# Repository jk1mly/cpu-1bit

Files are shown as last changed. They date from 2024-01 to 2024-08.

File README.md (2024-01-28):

# cpu-1bit
MC14500 1bit CPU

MC14500Bを使って実験を行うための基板と、プログラムをEPROMの代わりにPICに入れるソフト
MC14500Bのソフトはprogcd.hに記述
ニーモニックどはopcode.hに定義
main.cはアドレスに従ってデータを出すのみ
PICでの遅延が大きいので16F1938を32Mで動かしている
（あくまでもMC14500Bを使うのが目的）

ICソケットに実装する前に電源のショートなど確認する
電池を入れて電源を供給、PWRのLEDで電源極性を確認
電源を切ってICを実装、向きがバラバラなので注意
J3はS；スロー側に設定、ジャンパポストはオープンで良い
IN(J10)とOUT(J4)のb1、INのb2をGND(J6 3)、b3を+V(J6 1)に接続
（テスト用のプログラムだけならb3のみで良い、接続はプログラムに依存）
電源を入れて異常がなければPICkitを接続
（PICkitからは電源を供給しない・デフォルト）
PICにプログラムしたらPICkitを外す
RUNのスイッチを押すとプルグラムが動く

（PICで動かすなら3Vか4.5V）
SW4を押すとCPUがリセットされる
同時にROMアドレスの上位が1になりEPROMの書き込んでない領域になる
これによりCPUにはFが入力されるのでFLGFが出てぷrグラムカウンタが0になる
試験用のプログラムはDIPスイッチのNOT, AND, OR, XORをLEDに表示する

改善点
SW4とパラに0.1uFを入れておいた方が良い
（電源ON時にリセット状態で止められる・動かしたいならSW3）
RUNとWRITEのLEDを付けておいた方が良い
データとして0,1、ラッチしたデータを読める入力があった方が良い
（ジャンパするよう基板を作ってあるが、ジャンパポストを設けるべき）
ラッチ4ビットのLEDに入れる抵抗は別回路な方が良い
（外部I/Oで使うための抵抗と兼用になっている）

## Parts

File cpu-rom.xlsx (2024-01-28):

# | Reference | Qty | Value | Footprint |  | Akizuki
1 | C1, C2, C3, C4, C5, C7, C9, C10, C11, C13, C14, C15 | 12 | 0.1u | 積層磁器コン |  | 113582
2 | C6, C8 | 2 | 1000p | 積層磁器コン |  | 104062
3 | C12 | 1 | 10u | 電界コン |  | 117897
4 | D1, D2, D3, D4 | 7 | LED | LED 緑 |  | 111639
 | D6, D7, D8 | 3 | LED | LED 黄 |  | 111637
5 | D5 | 1 | D | スイッチングダイオード |  | 100941
6 | IC1 | 1 | MC14001 | NOR |  | 114536
7 | IC2 | 1 | MC14099 | ラッチ |  |  | Sato
8 | IC3 | 1 | PIC16F1938 | PIC（ROM代用） |  | 104357
9 | IC4 | 1 | MC14049 | INV |  | 109417
10 | IC5 | 1 | MC14500B | 1bit CPU |  |  | AliEx
11 | IC6 | 1 | TMM2764 | EPROM | 未実装 |  | Suzusho
12 | IC7 | 1 | MC14011 | NAND |  | 113729
13 | IC8 | 1 | MC14520 | カウンタ |  | 110918
14 | IC9 | 1 | MC14512 | セレクタ |  |  | Sato
 | IC1,7 | 2 |  | Socket 14P |  | 100029
 | IC2,4,5,8,9 | 5 |  | Socket 16P |  | 100029
 | IC3 | 1 |  | Socket 28P 300mil |  | 101339
 | IC6 | 1 |  | Socket 28P 600mil |  | 100033
15 | J1 | 1 | Conn_06 | PICkit接続用 |  | 112247
16 | J2, J7, J8 | 4 | Conn_01x03_Pin | ジャンパポスト |  | 112247
 | J2, J7, J8 | 1 |  | ジャンパピン |  | 103691
 | J3 | 1 |  | スイッチ |  | 115707
17 | J4, J5, J10, J11 | 4 | Conn_08 | 外部接続用 |  | 100082
18 | J6 | 1 | Conn_01x05_Pin | 外部接続用 |  | 112247
19 | J9 | 1 | Conn_02 | 電池用 |  | 112247
 | J9 | 1 |  | 電池ケース |  | 112244
20 | R1, R2, R4, R6, R7, R19, R31, R32 | 8 | 10k | 抵抗 |  | 118208
21 | R3, R5, R8, R9, R10, R11, R12, R13, R14, R15, R23, R26, R29, R30, R35, R36, R39, R40, R44, R45 | 20 | 100 | 抵抗 |  | 118208
22 | R16 | 1 | 1M | 抵抗 |  | 125105
23 | R17 | 1 | 47k | 抵抗 |  | 118208
24 | R18 | 1 | 1k | 抵抗 | 未実装
25 | R20 | 1 | 22 | 抵抗 |  | 125221
26 | R21 | 1 | 220 | 抵抗 |  | 125221
27 | R22, R24, R41 | 3 | 470 | 抵抗 |  | 125471
28 | R25, R27, R28, R33, R34, R37, R38, R42, R43 | 9 | 100k | 抵抗 |  | 125104
29 | SW1, SW2, SW3, SW4 | 4 | SW_Push | タクトスイッチ |  | 108080
30 | SW5 | 1 | SW_DIP_x04 | DIPスイッチ |  | 115243
31 | TP1, TP2, TP3, TP4 | 4 | M2.6 | スペーサ | 未実装 | 107318
 | TP1, TP2, TP3, TP4 | 4 | M2.6 | ナット | 未実装 | 114371
32 | TP5, TP6 | 2 |  | チェック端子 | 未実装 | 107591

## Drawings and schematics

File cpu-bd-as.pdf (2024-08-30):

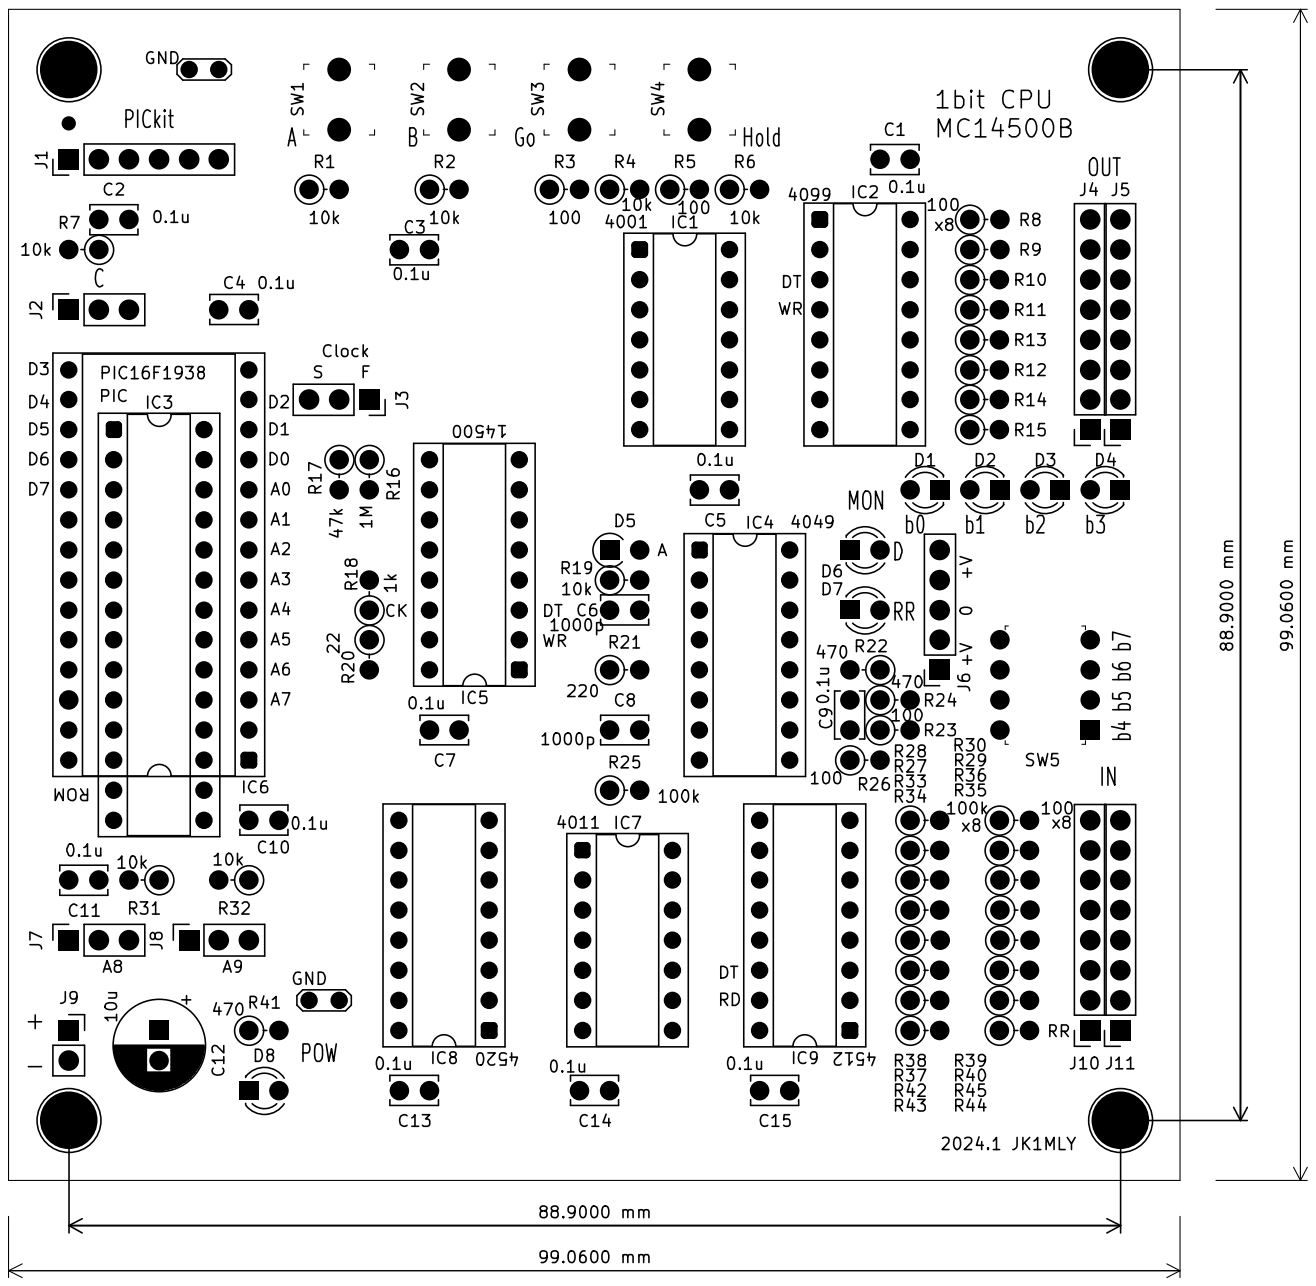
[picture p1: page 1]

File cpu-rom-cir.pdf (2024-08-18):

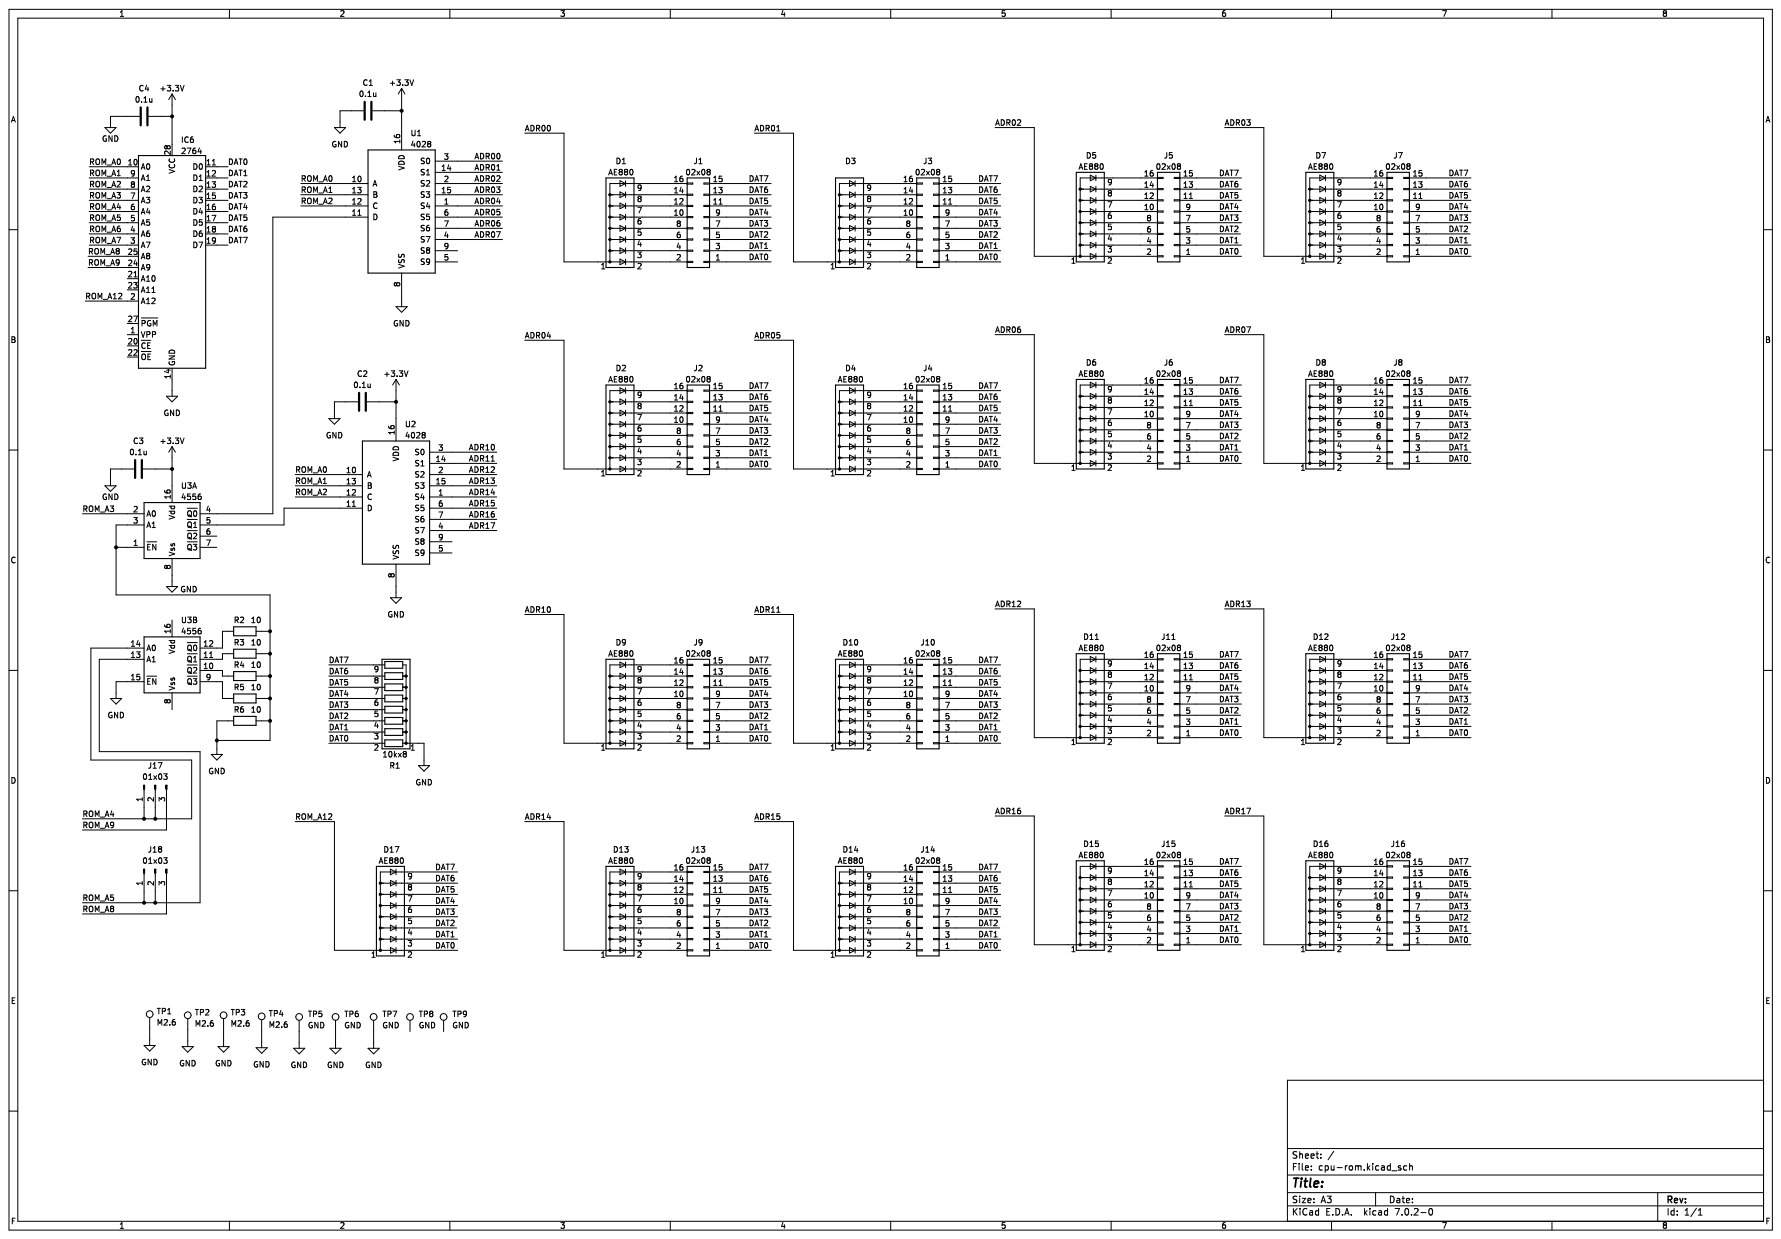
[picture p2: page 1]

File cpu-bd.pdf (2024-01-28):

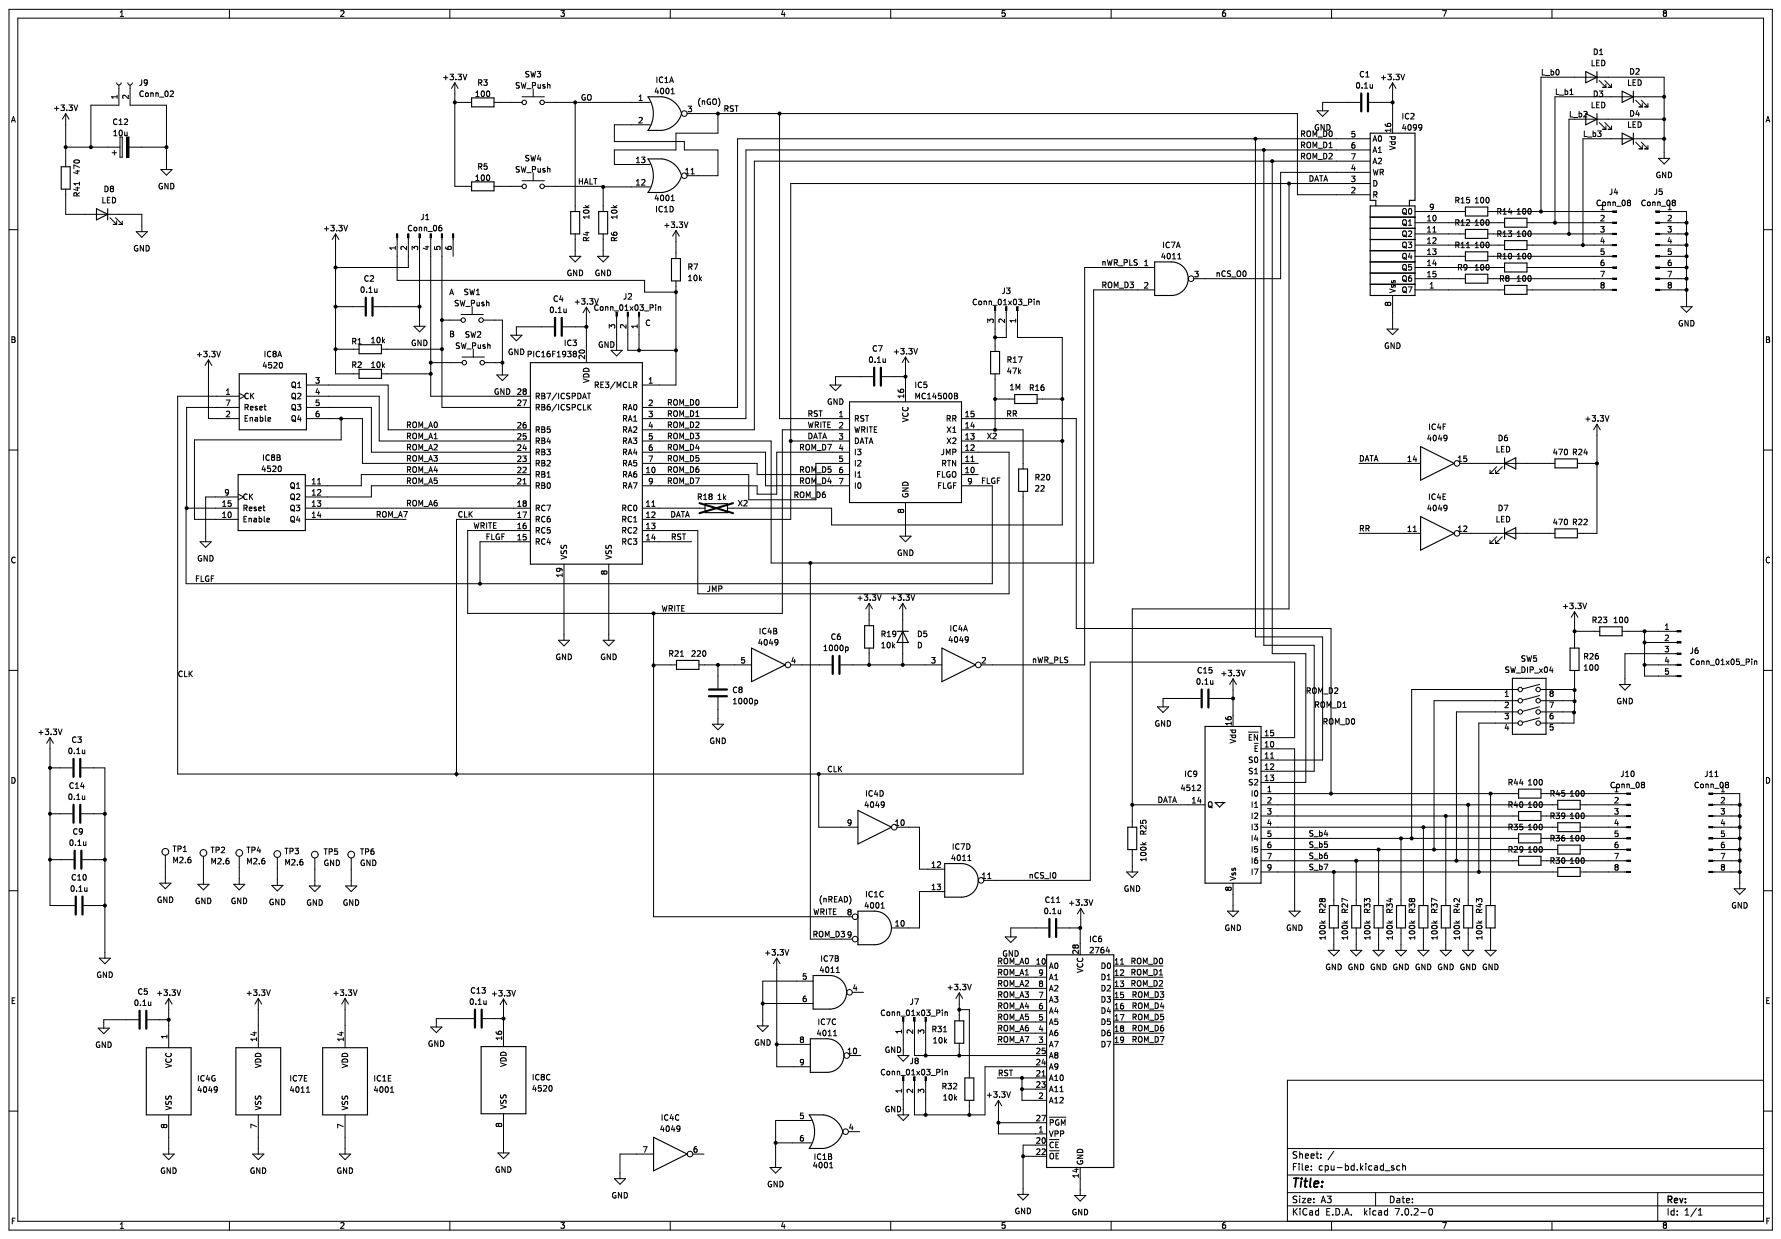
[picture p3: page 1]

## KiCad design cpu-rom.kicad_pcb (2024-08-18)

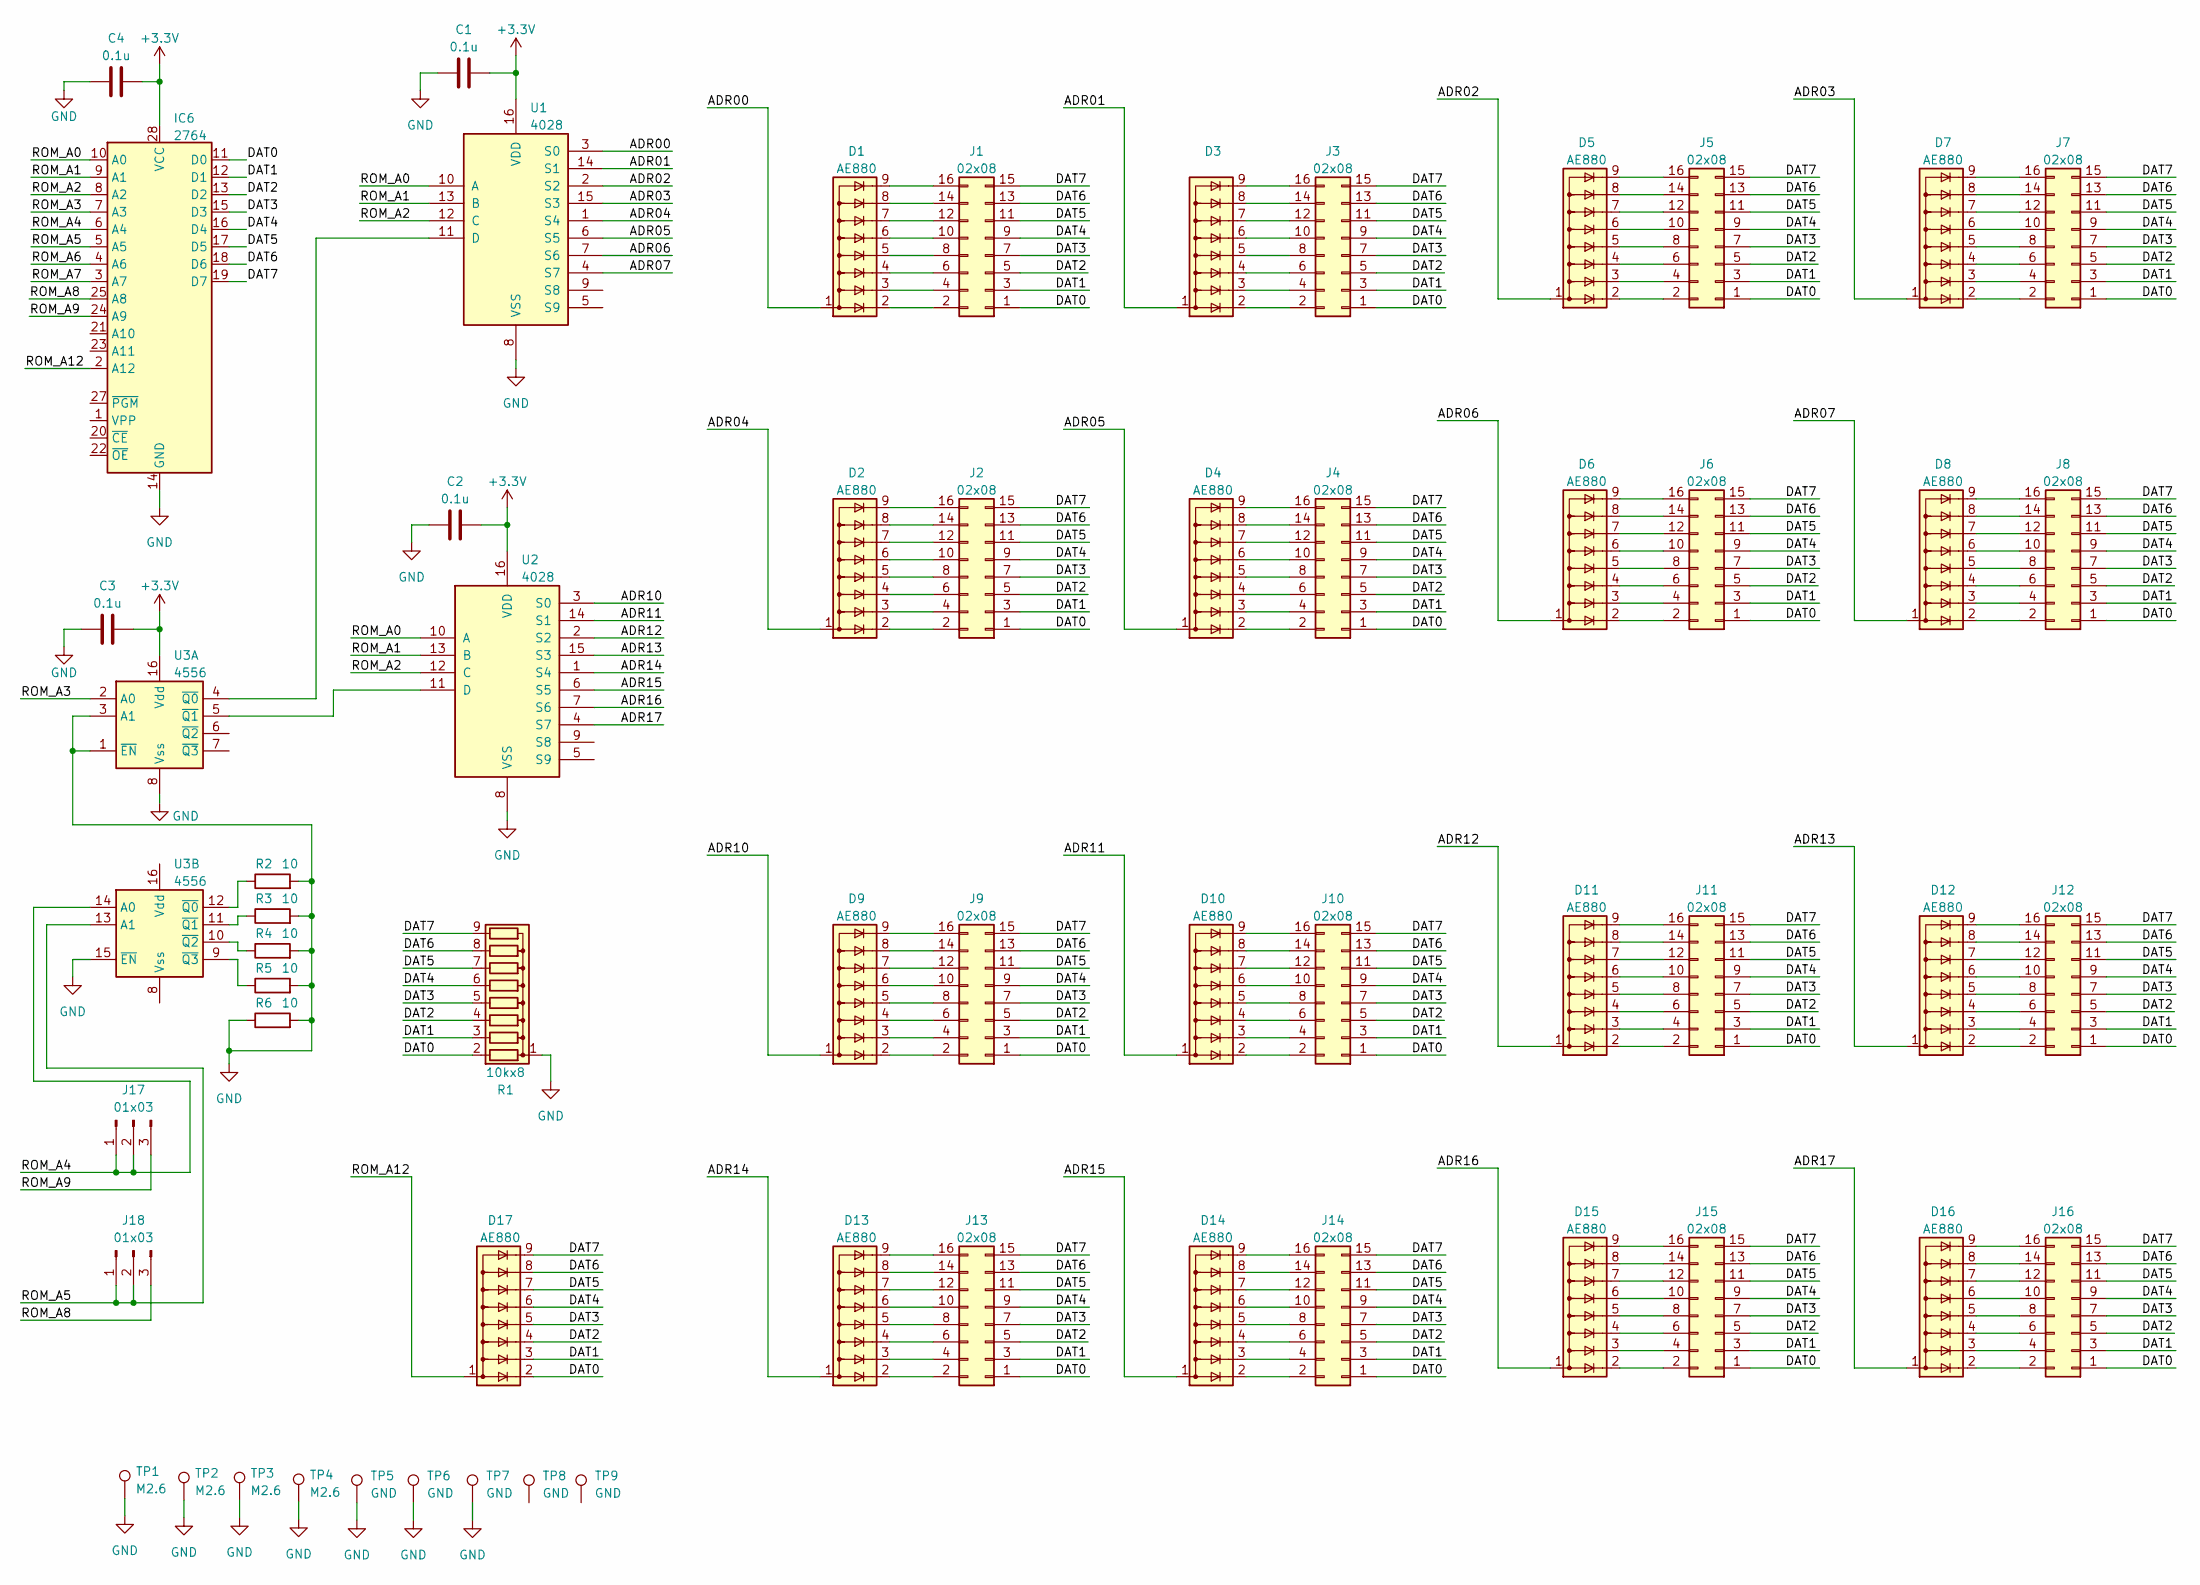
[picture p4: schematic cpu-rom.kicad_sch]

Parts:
C1, C2, C3, C4: 0.1u; C_Disc_P2.54mm
D1, D2, D3, D4, D5, D6, D7, D8, D9, D10, D11, D12, D13, D14, D15, D16, D17: AE880; R_Array_SIP9
IC6: 2764; DIP-28_W15.24mm_Socket_mini
J1, J2, J3, J4, J5, J6, J7, J8, J9, J10, J11, J12, J13, J14, J15, J16: 02x08; PinHeader_2x08_P2.54mm_Vertical
J17, J18: 01x03; PinHeader_1x03_P2.54mm_Vertical
R1: 10kx8; R_Array_SIP9
R2, R3, R4, R5, R6: 10; R_Axial_DIN0207_L6.3mm_D2.2mm_P2.54mm_Vertical
TP1, TP2, TP3, TP4: M2.6; TestPoint_Drill3mm
TP5, TP6, TP7, TP8, TP9: GND; TestPoint_2Pads_Pitch2.54mm_Drill0.8mm
U1, U2: 4028; DIP-16_W7.62mm_Socket_mini
U3: 4556; DIP-16_W7.62mm_Socket_mini

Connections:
+3.3V: C1.2, C2.2, C3.2, C4.2, IC6.28 (VCC), U1.16 (VDD), U2.16 (VDD), U3.16 (Vdd)
/ADR00: D1.1 (common), U1.3 (S0)
/ADR01: D3.1 (common), U1.14 (S1)
/ADR02: D5.1 (common), U1.2 (S2)
/ADR03: D7.1 (common), U1.15 (S3)
/ADR04: D2.1 (common), U1.1 (S4)
/ADR05: D4.1 (common), U1.6 (S5)
/ADR06: D6.1 (common), U1.7 (S6)
/ADR07: D8.1 (common), U1.4 (S7)
/ADR10: D9.1 (common), U2.3 (S0)
/ADR11: D10.1 (common), U2.14 (S1)
/ADR12: D11.1 (common), U2.2 (S2)
/ADR13: D12.1 (common), U2.15 (S3)
/ADR14: D13.1 (common), U2.1 (S4)
/ADR15: D14.1 (common), U2.6 (S5)
/ADR16: D15.1 (common), U2.7 (S6)
/ADR17: D16.1 (common), U2.4 (S7)
/DAT0: D17.2 (R1), IC6.11 (D0), J1.1, J2.1, J3.1, J4.1, J5.1, J6.1, J7.1, J8.1, J9.1, J10.1, J11.1, J12.1, J13.1, J14.1, J15.1, J16.1, R1.2 (R1)
/DAT1: D17.3 (R2), IC6.12 (D1), J1.3, J2.3, J3.3, J4.3, J5.3, J6.3, J7.3, J8.3, J9.3, J10.3, J11.3, J12.3, J13.3, J14.3, J15.3, J16.3, R1.3 (R2)
/DAT2: D17.4 (R3), IC6.13 (D2), J1.5, J2.5, J3.5, J4.5, J5.5, J6.5, J7.5, J8.5, J9.5, J10.5, J11.5, J12.5, J13.5, J14.5, J15.5, J16.5, R1.4 (R3)
/DAT3: D17.5 (R4), IC6.15 (D3), J1.7, J2.7, J3.7, J4.7, J5.7, J6.7, J7.7, J8.7, J9.7, J10.7, J11.7, J12.7, J13.7, J14.7, J15.7, J16.7, R1.5 (R4)
/DAT4: D17.6 (R5), IC6.16 (D4), J1.9, J2.9, J3.9, J4.9, J5.9, J6.9, J7.9, J8.9, J9.9, J10.9, J11.9, J12.9, J13.9, J14.9, J15.9, J16.9, R1.6 (R5)
/DAT5: D17.7 (R6), IC6.17 (D5), J1.11, J2.11, J3.11, J4.11, J5.11, J6.11, J7.11, J8.11, J9.11, J10.11, J11.11, J12.11, J13.11, J14.11, J15.11, J16.11, R1.7 (R6)
/DAT6: D17.8 (R7), IC6.18 (D6), J1.13, J2.13, J3.13, J4.13, J5.13, J6.13, J7.13, J8.13, J9.13, J10.13, J11.13, J12.13, J13.13, J14.13, J15.13, J16.13, R1.8 (R7)
/DAT7: D17.9 (R8), IC6.19 (D7), J1.15, J2.15, J3.15, J4.15, J5.15, J6.15, J7.15, J8.15, J9.15, J10.15, J11.15, J12.15, J13.15, J14.15, J15.15, J16.15, R1.9 (R8)
/ROM_A0: IC6.10 (A0), U1.10 (A), U2.10 (A)
/ROM_A1: IC6.9 (A1), U1.13 (B), U2.13 (B)
/ROM_A2: IC6.8 (A2), U1.12 (C), U2.12 (C)
/ROM_A3: IC6.7 (A3), U3.2 (A0)
/ROM_A4: IC6.6 (A4), J17.1, J17.2, U3.14 (A0)
/ROM_A5: IC6.5 (A5), J18.1, J18.2, U3.13 (A1)
/ROM_A6: IC6.4 (A6)
/ROM_A7: IC6.3 (A7)
/ROM_A8: IC6.25 (A8), J18.3
/ROM_A9: IC6.24 (A9), J17.3
/ROM_A12: D17.1 (common), IC6.2 (A12)
GND: C1.1, C2.1, C3.1, C4.1, IC6.14 (GND), R1.1 (common), R2.2, R3.2, R4.2, R5.2, R6.1, R6.2, TP1.1, TP2.1, TP3.1, TP4.1, TP5.1, TP6.1, TP7.1, U1.8 (VSS), U2.8 (VSS), U3.1 (~EN), U3.3 (A1), U3.8 (Vss), U3.15 (~EN)
unnamed: D1.2 (R1), J1.2
unnamed: D1.3 (R2), J1.4
unnamed: D1.4 (R3), J1.6
unnamed: D1.5 (R4), J1.8
unnamed: D1.6 (R5), J1.10
unnamed: D1.7 (R6), J1.12
unnamed: D1.8 (R7), J1.14
unnamed: D1.9 (R8), J1.16
unnamed: D2.2 (R1), J2.2
unnamed: D2.3 (R2), J2.4
unnamed: D2.4 (R3), J2.6
unnamed: D2.5 (R4), J2.8
unnamed: D2.6 (R5), J2.10
unnamed: D2.7 (R6), J2.12
unnamed: D2.8 (R7), J2.14
unnamed: D2.9 (R8), J2.16
unnamed: D3.2 (R1), J3.2
unnamed: D3.3 (R2), J3.4
unnamed: D3.4 (R3), J3.6
unnamed: D3.5 (R4), J3.8
unnamed: D3.6 (R5), J3.10
unnamed: D3.7 (R6), J3.12
unnamed: D3.8 (R7), J3.14
unnamed: D3.9 (R8), J3.16
unnamed: D4.2 (R1), J4.2
unnamed: D4.3 (R2), J4.4
unnamed: D4.4 (R3), J4.6
unnamed: D4.5 (R4), J4.8
unnamed: D4.6 (R5), J4.10
unnamed: D4.7 (R6), J4.12
unnamed: D4.8 (R7), J4.14
unnamed: D4.9 (R8), J4.16
unnamed: D5.2 (R1), J5.2
unnamed: D5.3 (R2), J5.4
unnamed: D5.4 (R3), J5.6
unnamed: D5.5 (R4), J5.8
unnamed: D5.6 (R5), J5.10
unnamed: D5.7 (R6), J5.12
unnamed: D5.8 (R7), J5.14
unnamed: D5.9 (R8), J5.16
unnamed: D6.2 (R1), J6.2
unnamed: D6.3 (R2), J6.4
unnamed: D6.4 (R3), J6.6
unnamed: D6.5 (R4), J6.8
unnamed: D6.6 (R5), J6.10
unnamed: D6.7 (R6), J6.12
unnamed: D6.8 (R7), J6.14
unnamed: D6.9 (R8), J6.16
unnamed: D7.2 (R1), J7.2
unnamed: D7.3 (R2), J7.4
unnamed: D7.4 (R3), J7.6
unnamed: D7.5 (R4), J7.8
unnamed: D7.6 (R5), J7.10
unnamed: D7.7 (R6), J7.12
unnamed: D7.8 (R7), J7.14
unnamed: D7.9 (R8), J7.16
unnamed: D8.2 (R1), J8.2
unnamed: D8.3 (R2), J8.4
unnamed: D8.4 (R3), J8.6
unnamed: D8.5 (R4), J8.8
unnamed: D8.6 (R5), J8.10
unnamed: D8.7 (R6), J8.12
unnamed: D8.8 (R7), J8.14
unnamed: D8.9 (R8), J8.16
unnamed: D9.2 (R1), J9.2
unnamed: D9.3 (R2), J9.4
unnamed: D9.4 (R3), J9.6
unnamed: D9.5 (R4), J9.8
unnamed: D9.6 (R5), J9.10
unnamed: D9.7 (R6), J9.12
unnamed: D9.8 (R7), J9.14
unnamed: D9.9 (R8), J9.16
unnamed: D10.2 (R1), J10.2
unnamed: D10.3 (R2), J10.4
unnamed: D10.4 (R3), J10.6
unnamed: D10.5 (R4), J10.8
unnamed: D10.6 (R5), J10.10
unnamed: D10.7 (R6), J10.12
unnamed: D10.8 (R7), J10.14
unnamed: D10.9 (R8), J10.16
unnamed: D11.2 (R1), J11.2
unnamed: D11.3 (R2), J11.4
unnamed: D11.4 (R3), J11.6
unnamed: D11.5 (R4), J11.8
unnamed: D11.6 (R5), J11.10
unnamed: D11.7 (R6), J11.12
unnamed: D11.8 (R7), J11.14
unnamed: D11.9 (R8), J11.16
unnamed: D12.2 (R1), J12.2
unnamed: D12.3 (R2), J12.4
unnamed: D12.4 (R3), J12.6
unnamed: D12.5 (R4), J12.8
unnamed: D12.6 (R5), J12.10
unnamed: D12.7 (R6), J12.12
unnamed: D12.8 (R7), J12.14
unnamed: D12.9 (R8), J12.16
unnamed: D13.2 (R1), J13.2
unnamed: D13.3 (R2), J13.4
unnamed: D13.4 (R3), J13.6
unnamed: D13.5 (R4), J13.8
unnamed: D13.6 (R5), J13.10
unnamed: D13.7 (R6), J13.12
unnamed: D13.8 (R7), J13.14
unnamed: D13.9 (R8), J13.16
unnamed: D14.2 (R1), J14.2
unnamed: D14.3 (R2), J14.4
unnamed: D14.4 (R3), J14.6
unnamed: D14.5 (R4), J14.8
unnamed: D14.6 (R5), J14.10
unnamed: D14.7 (R6), J14.12
unnamed: D14.8 (R7), J14.14
unnamed: D14.9 (R8), J14.16
unnamed: D15.2 (R1), J15.2
unnamed: D15.3 (R2), J15.4
unnamed: D15.4 (R3), J15.6
unnamed: D15.5 (R4), J15.8
unnamed: D15.6 (R5), J15.10
unnamed: D15.7 (R6), J15.12
unnamed: D15.8 (R7), J15.14
unnamed: D15.9 (R8), J15.16
unnamed: D16.2 (R1), J16.2
unnamed: D16.3 (R2), J16.4
unnamed: D16.4 (R3), J16.6
unnamed: D16.5 (R4), J16.8
unnamed: D16.6 (R5), J16.10
unnamed: D16.7 (R6), J16.12
unnamed: D16.8 (R7), J16.14
unnamed: D16.9 (R8), J16.16
unnamed: U1.11 (D), U3.4 (~Q0)
unnamed: U2.11 (D), U3.5 (~Q1)
unnamed: R2.1, U3.12 (~Q0)
unnamed: R3.1, U3.11 (~Q1)
unnamed: R4.1, U3.10 (~Q2)
unnamed: R5.1, U3.9 (~Q3)

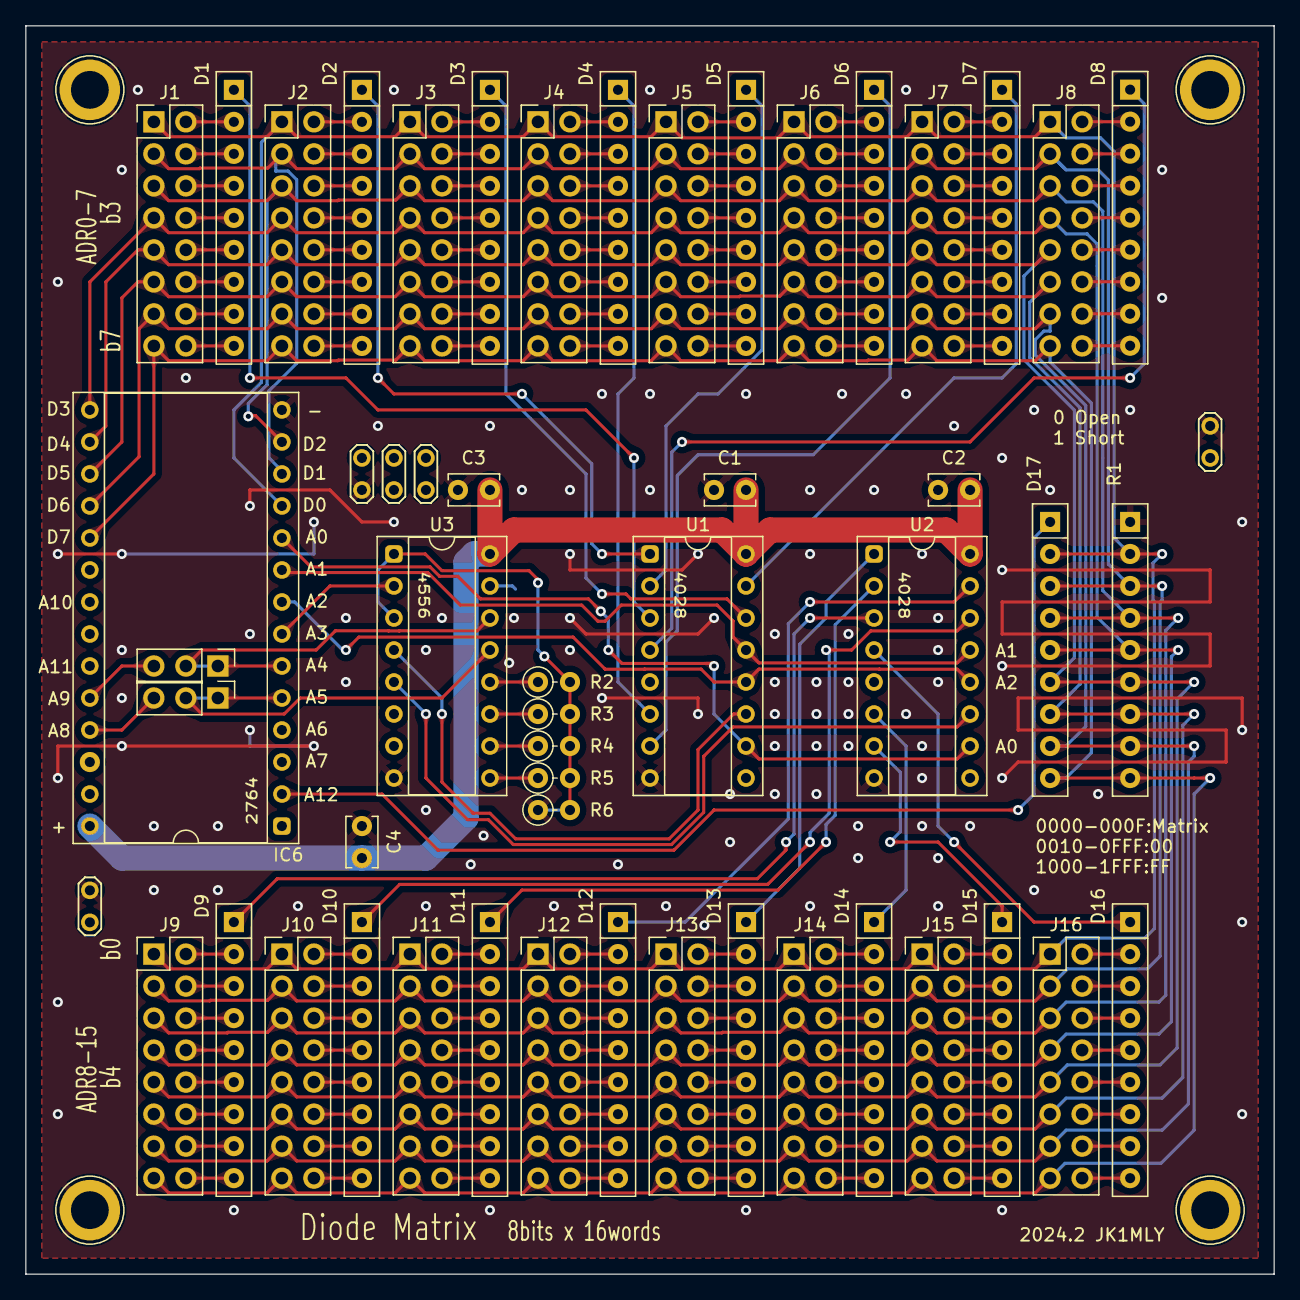
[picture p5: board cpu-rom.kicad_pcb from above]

Board: 2 copper layers, 99.1 x 99.1 mm, 58 parts (0 on the bottom side), 169 nets.

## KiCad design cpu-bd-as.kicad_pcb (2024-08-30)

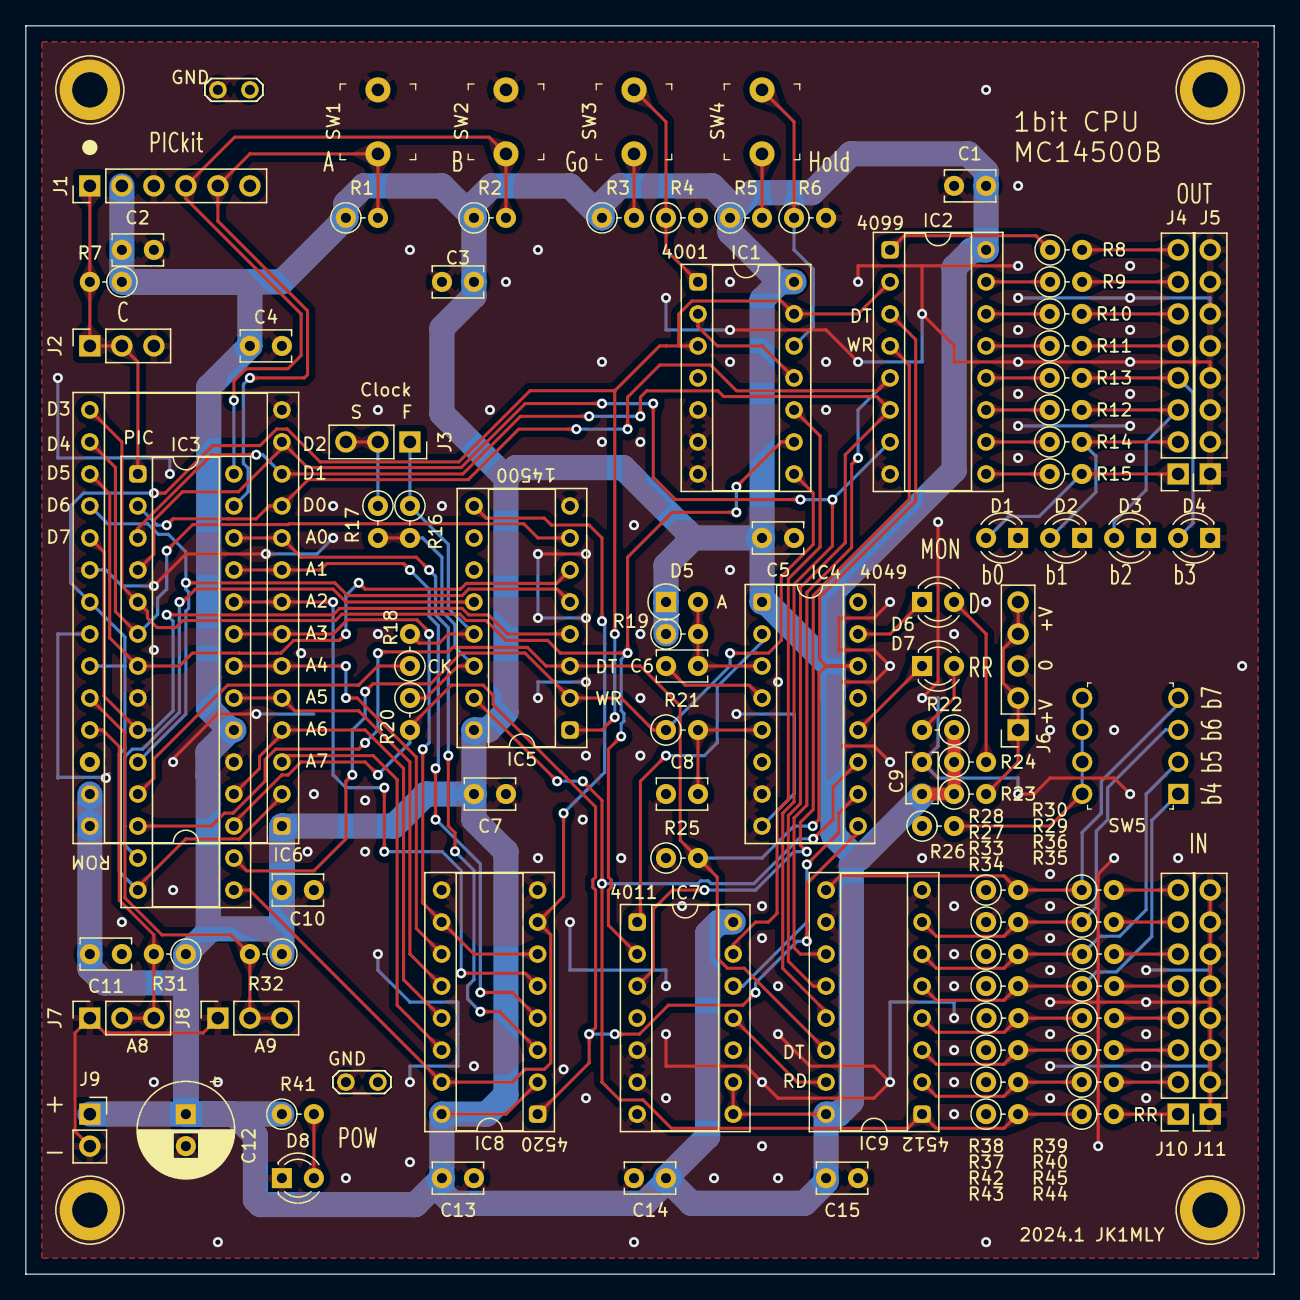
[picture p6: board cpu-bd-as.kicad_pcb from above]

Board: 2 copper layers, 99.1 x 99.1 mm, 99 parts (0 on the bottom side), 85 nets.

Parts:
C1, C2, C3, C4, C5, C7, C9, C10, C11, C13, C14, C15: 0.1u; C_Disc_P2.54mm
C6, C8: 1000p; C_Disc_P2.54mm
C12: 10u; CP_Radial_D7.5mm_P2.54mm
D1, D2, D3, D4, D6, D7, D8: LED; LED_D3.0mm
D5: D; D_A-405_P2.54mm_Vertical_AnodeUp
IC1: 4001; DIP-14_W7.62mm_Socket_mini
IC2: 4099; DIP-16_W7.62mm_Socket_mini
IC3: PIC16F1938; DIP-28_W7.62mm_Socket_mini
IC4: 4049; DIP-16_W7.62mm_Socket_mini
IC5: MC14500B; DIP-16_W7.62mm_Socket_mini
IC6: 2764; DIP-28_W15.24mm_Socket_mini
IC7: 4011; DIP-14_W7.62mm_Socket_mini
IC8: 4520; DIP-16_W7.62mm_Socket_mini
IC9: 4512; DIP-16_W7.62mm_Socket_mini
J1: Conn_06; PinHeader_1x06_P2.54mm_Vertical
J2, J3, J7, J8: Conn_01x03_Pin; PinSocket_1x03_P2.54mm_Vertical
J4, J5, J10, J11: Conn_08; PinSocket_1x08_P2.54mm_Vertical
J6: Conn_01x05_Pin; PinSocket_1x05_P2.54mm_Vertical
J9: Conn_02; PinSocket_1x02_P2.54mm_Vertical
R1, R2, R4, R6, R7, R19, R31, R32: 10k; R_Axial_DIN0207_L6.3mm_D2.2mm_P2.54mm_Vertical
R3, R5, R8, R9, R10, R11, R12, R13, R14, R15, R23, R26, R29, R30, R35, R36, R39, R40, R44, R45: 100; R_Axial_DIN0207_L6.3mm_D2.2mm_P2.54mm_Vertical
R16: 1M; R_Axial_DIN0207_L6.3mm_D2.2mm_P2.54mm_Vertical
R17: 47k; R_Axial_DIN0207_L6.3mm_D2.2mm_P2.54mm_Vertical
R18: 1k; R_Axial_DIN0207_L6.3mm_D2.2mm_P2.54mm_Vertical
R20: 22; R_Axial_DIN0207_L6.3mm_D2.2mm_P2.54mm_Vertical
R21: 220; R_Axial_DIN0207_L6.3mm_D2.2mm_P2.54mm_Vertical
R22, R24, R41: 470; R_Axial_DIN0207_L6.3mm_D2.2mm_P2.54mm_Vertical
R25, R27, R28, R33, R34, R37, R38, R42, R43: 100k; R_Axial_DIN0207_L6.3mm_D2.2mm_P2.54mm_Vertical
SW1, SW2, SW3, SW4: SW_Push; Switch_2P
SW5: SW_DIP_x04; DIP-8_W7.62mm
TP1, TP2, TP3, TP4: M2.6; TestPoint_Loop_D3.80mm_Drill2.8mm
TP5, TP6: GND; TestPoint_2Pads_Pitch2.54mm_Drill0.8mm

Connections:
+3.3V: C1.2, C2.1, C3.1, C4.2, C5.2, C7.2, C9.1, C10.1, C11.2, C12.1, C13.2, C14.1, C15.2, D5.1 (K), IC1.14 (VDD), IC2.16 (Vdd), IC3.20 (VDD), IC4.1 (VCC), IC5.16 (VCC), IC6.1 (VPP), IC6.27 (~PGM), IC6.28 (VCC), IC7.8, IC7.9, IC7.14 (VDD), IC8.2 (Enable), IC8.16 (VDD), IC9.16 (Vdd), J1.2, J9.1, R1.1, R2.1, R3.1, R5.1, R7.1, R19.1, R22.1, R23.1, R24.1, R26.1, R31.1, R32.1, R41.1
/CLK: IC3.17 (RC6), IC4.9, IC8.1 (CK), R20.2
/DATA: IC2.3 (D), IC3.12 (RC1), IC4.14, IC5.3 (DATA), IC9.14 (Q), R25.2
/FLGF: IC3.15 (RC4), IC5.9 (FLGF), IC8.7 (Reset), IC8.15 (Reset)
/GO: IC1.1, R4.1, SW3.2
/HALT: IC1.12, R6.1, SW4.2
/JMP: IC3.13 (RC2), IC5.12 (JMP)
/L_b0: D1.2 (A), J4.1, R15.2
/L_b1: D2.2 (A), J4.2, R14.2
/L_b2: D3.2 (A), J4.3, R12.2
/L_b3: D4.2 (A), J4.4, R13.2
/ROM_A0: IC3.26 (RB5), IC6.10 (A0), IC8.3 (Q1)
/ROM_A1: IC3.25 (RB4), IC6.9 (A1), IC8.4 (Q2)
/ROM_A2: IC3.24 (RB3), IC6.8 (A2), IC8.5 (Q3)
/ROM_A3: IC3.23 (RB2), IC6.7 (A3), IC8.6 (Q4), IC8.10 (Enable)
/ROM_A4: IC3.22 (RB1), IC6.6 (A4), IC8.11 (Q1)
/ROM_A5: IC3.21 (RB0), IC6.5 (A5), IC8.12 (Q2)
/ROM_A6: IC3.18 (RC7), IC6.4 (A6), IC8.13 (Q3)
/ROM_A7: IC6.3 (A7), IC8.14 (Q4)
/ROM_D0: IC2.5 (A0), IC3.2 (RA0), IC6.11 (D0), IC9.11 (S0)
/ROM_D1: IC2.6 (A1), IC3.3 (RA1), IC6.12 (D1), IC9.12 (S1)
/ROM_D2: IC2.7 (A2), IC3.4 (RA2), IC6.13 (D2), IC9.13 (S2)
/ROM_D3: IC1.9, IC3.5 (RA3), IC6.15 (D3), IC7.2
/ROM_D4: IC3.6 (RA4), IC5.7 (I0), IC6.16 (D4)
/ROM_D5: IC3.7 (RA5), IC5.6 (I1), IC6.17 (D5)
/ROM_D6: IC3.10 (RA6), IC5.5 (I2), IC6.18 (D6)
/ROM_D7: IC3.9 (RA7), IC5.4 (I3), IC6.19 (D7)
/RR: IC4.11, IC5.15 (RR), IC9.1 (I0), R43.2, R44.1
/RST: IC1.3, IC1.13, IC2.2 (R), IC3.14 (RC3), IC5.1 (RST), IC6.2 (A12), IC6.21 (A10), IC6.23 (A11)
/S_b4: IC9.5 (I4), R34.2, R35.1, SW5.1
/S_b5: IC9.6 (I5), R33.2, R36.1, SW5.2
/S_b6: IC9.7 (I6), R27.2, R29.1, SW5.3
/S_b7: IC9.9 (I7), R28.2, R30.1, SW5.4
/WRITE: IC1.8, IC3.16 (RC5), IC5.2 (WRITE), R21.1
/X2: IC5.13 (X2), J3.1, R16.1, R18.2
/nCS_I0: IC7.11, IC9.15 (~EN)
/nCS_O0: IC2.4 (WR), IC7.3
/nWR_PLS: IC4.2, IC7.1
GND: C1.1, C2.2, C3.2, C4.1, C5.1, C7.1, C8.2, C9.2, C10.2, C12.2, C13.1, C14.2, C15.1, D1.1 (K), D2.1 (K), D3.1 (K), D4.1 (K), D8.1 (K), IC1.5, IC1.6, IC1.7 (VSS), IC2.8 (Vss), IC3.8 (VSS), IC3.19 (VSS), IC4.7, IC4.8 (VSS), IC5.8 (GND), IC6.14 (GND), IC6.20 (~CE), IC6.22 (~OE), IC7.5, IC7.6, IC7.7 (VSS), IC8.8 (VSS), IC8.9 (CK), IC9.8 (Vss), IC9.10 (~E), J1.3, J2.3, J5.1, J5.2, J5.3, J5.4, J5.5, J5.6, J5.7, J5.8, J6.3, J7.1, J8.1, J9.2, J11.1, J11.2, J11.3, J11.4, J11.5, J11.6, J11.7, J11.8, R4.2, R6.2, R25.1, R27.1, R28.1, R33.1, R34.1, R37.1, R38.1, R42.1, R43.1, SW1.2, SW2.2, TP1.1, TP2.1, TP3.1, TP4.1, TP5.1, TP6.1
unnamed: C6.1, IC4.4
unnamed: C8.1, IC4.5, R21.2
unnamed: C6.2, D5.2 (A), IC4.3, R19.2
unnamed: D6.2 (A), R24.2
unnamed: D6.1 (K), IC4.15
unnamed: D7.2 (A), R22.2
unnamed: D7.1 (K), IC4.12
unnamed: D8.2 (A), R41.2
unnamed: IC1.10, IC7.13
unnamed: IC1.2, IC1.11
unnamed: IC2.9 (Q0), R15.1
unnamed: IC2.10 (Q1), R14.1
unnamed: IC2.11 (Q2), R12.1
unnamed: IC2.12 (Q3), R13.1
unnamed: IC2.13 (Q4), R11.1
unnamed: IC2.14 (Q5), R10.1
unnamed: IC2.15 (Q6), R9.1
unnamed: IC2.1 (Q7), R8.1
unnamed: IC3.27 (RB6/ICSPCLK), J1.5, R1.2, SW1.1
unnamed: IC3.28 (RB7/ICSPDAT), J1.4, R2.2, SW2.1
unnamed: IC3.11 (RC0), R18.1
unnamed: IC3.1 (RE3/MCLR), J1.1, J2.1, J2.2, R7.2
unnamed: IC4.10, IC7.12
unnamed: IC5.14 (X1), R16.2, R17.2, R20.1
unnamed: IC6.25 (A8), J7.2, J7.3, R31.2
unnamed: IC6.24 (A9), J8.2, J8.3, R32.2
unnamed: IC9.2 (I1), R42.2, R45.1
unnamed: IC9.3 (I2), R37.2, R40.1
unnamed: IC9.4 (I3), R38.2, R39.1
unnamed: J3.2, J3.3, R17.1
unnamed: J4.5, R11.2
unnamed: J4.6, R10.2
unnamed: J4.7, R9.2
unnamed: J4.8, R8.2
unnamed: J6.1, J6.2, J6.4, J6.5, R23.2
unnamed: J10.1, R44.2
unnamed: J10.2, R45.2
unnamed: J10.3, R40.2
unnamed: J10.4, R39.2
unnamed: J10.5, R35.2
unnamed: J10.6, R36.2
unnamed: J10.7, R29.2
unnamed: J10.8, R30.2
unnamed: R3.2, SW3.1
unnamed: R5.2, SW4.1
unnamed: R26.2, SW5.5, SW5.6, SW5.7, SW5.8

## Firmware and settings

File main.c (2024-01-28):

/**
  Generated Main Source File

  Company:
    Microchip Technology Inc.

  File Name:
    main.c

  Summary:
    This is the main file generated using PIC10 / PIC12 / PIC16 / PIC18 MCUs

  Description:
    This header file provides implementations for driver APIs for all modules selected in the GUI.
    Generation Information :
        Product Revision  :  PIC10 / PIC12 / PIC16 / PIC18 MCUs - 1.81.8
        Device            :  PIC16F1933
        Driver Version    :  2.00
*/

/*
    (c) 2018 Microchip Technology Inc. and its subsidiaries. 
    
    Subject to your compliance with these terms, you may use Microchip software and any 
    derivatives exclusively with Microchip products. It is your responsibility to comply with third party 
    license terms applicable to your use of third party software (including open source software) that 
    may accompany Microchip software.
    
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
    IN NO EVENT WILL MICROCHIP BE LIABLE FOR ANY INDIRECT, SPECIAL, PUNITIVE, 
    INCIDENTAL OR CONSEQUENTIAL LOSS, DAMAGE, COST OR EXPENSE OF ANY KIND 
    WHATSOEVER RELATED TO THE SOFTWARE, HOWEVER CAUSED, EVEN IF MICROCHIP 
    HAS BEEN ADVISED OF THE POSSIBILITY OR THE DAMAGES ARE FORESEEABLE. TO 
    THE FULLEST EXTENT ALLOWED BY LAW, MICROCHIP'S TOTAL LIABILITY ON ALL 
    CLAIMS IN ANY WAY RELATED TO THIS SOFTWARE WILL NOT EXCEED THE AMOUNT 
    OF FEES, IF ANY, THAT YOU HAVE PAID DIRECTLY TO MICROCHIP FOR THIS 
    SOFTWARE.
*/

#include <stdio.h>
#include <stdint.h>
#include "progcd.h"
#include "mcc_generated_files/mcc.h"

/*
                         Main application
 */
void main(void)
{
    // initialize the device
    SYSTEM_Initialize();

    // When using interrupts, you need to set the Global and Peripheral Interrupt Enable bits
    // Use the following macros to:

    // Enable the Global Interrupts
    //INTERRUPT_GlobalInterruptEnable();

    // Enable the Peripheral Interrupts
    //INTERRUPT_PeripheralInterruptEnable();

    // Disable the Global Interrupts
    //INTERRUPT_GlobalInterruptDisable();

    // Disable the Peripheral Interrupts
    //INTERRUPT_PeripheralInterruptDisable();

    while (1){
        // Reset
        if (RC3 == 1) {
            PORTA   = 0xff;            
        } else {
            uint8_t rom_adr;
            rom_adr = RB1*16 + RB2*8 + RB3*4 + RB4*2 + RB5;
            PORTA   = pic_rom[rom_adr];
        }
    }
}
/**
 End of File
*/

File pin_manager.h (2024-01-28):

/**
  @Generated Pin Manager Header File

  @Company:
    Microchip Technology Inc.

  @File Name:
    pin_manager.h

  @Summary:
    This is the Pin Manager file generated using PIC10 / PIC12 / PIC16 / PIC18 MCUs

  @Description
    This header file provides APIs for driver for .
    Generation Information :
        Product Revision  :  PIC10 / PIC12 / PIC16 / PIC18 MCUs - 1.81.8
        Device            :  PIC16F1933
        Driver Version    :  2.11
    The generated drivers are tested against the following:
        Compiler          :  XC8 2.36 and above
        MPLAB 	          :  MPLAB X 6.00	
*/

/*
    (c) 2018 Microchip Technology Inc. and its subsidiaries. 
    
    Subject to your compliance with these terms, you may use Microchip software and any 
    derivatives exclusively with Microchip products. It is your responsibility to comply with third party 
    license terms applicable to your use of third party software (including open source software) that 
    may accompany Microchip software.
    
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
    IN NO EVENT WILL MICROCHIP BE LIABLE FOR ANY INDIRECT, SPECIAL, PUNITIVE, 
    INCIDENTAL OR CONSEQUENTIAL LOSS, DAMAGE, COST OR EXPENSE OF ANY KIND 
    WHATSOEVER RELATED TO THE SOFTWARE, HOWEVER CAUSED, EVEN IF MICROCHIP 
    HAS BEEN ADVISED OF THE POSSIBILITY OR THE DAMAGES ARE FORESEEABLE. TO 
    THE FULLEST EXTENT ALLOWED BY LAW, MICROCHIP'S TOTAL LIABILITY ON ALL 
    CLAIMS IN ANY WAY RELATED TO THIS SOFTWARE WILL NOT EXCEED THE AMOUNT 
    OF FEES, IF ANY, THAT YOU HAVE PAID DIRECTLY TO MICROCHIP FOR THIS 
    SOFTWARE.
*/

#ifndef PIN_MANAGER_H
#define PIN_MANAGER_H

/**
  Section: Included Files
*/

#include <xc.h>

#define INPUT   1
#define OUTPUT  0

#define HIGH    1
#define LOW     0

#define ANALOG      1
#define DIGITAL     0

#define PULL_UP_ENABLED      1
#define PULL_UP_DISABLED     0

// get/set IO_RA0 aliases
#define IO_RA0_TRIS                 TRISAbits.TRISA0
#define IO_RA0_LAT                  LATAbits.LATA0
#define IO_RA0_PORT                 PORTAbits.RA0
#define IO_RA0_ANS                  ANSELAbits.ANSA0
#define IO_RA0_SetHigh()            do { LATAbits.LATA0 = 1; } while(0)
#define IO_RA0_SetLow()             do { LATAbits.LATA0 = 0; } while(0)
#define IO_RA0_Toggle()             do { LATAbits.LATA0 = ~LATAbits.LATA0; } while(0)
#define IO_RA0_GetValue()           PORTAbits.RA0
#define IO_RA0_SetDigitalInput()    do { TRISAbits.TRISA0 = 1; } while(0)
#define IO_RA0_SetDigitalOutput()   do { TRISAbits.TRISA0 = 0; } while(0)
#define IO_RA0_SetAnalogMode()      do { ANSELAbits.ANSA0 = 1; } while(0)
#define IO_RA0_SetDigitalMode()     do { ANSELAbits.ANSA0 = 0; } while(0)

// get/set IO_RA1 aliases
#define IO_RA1_TRIS                 TRISAbits.TRISA1
#define IO_RA1_LAT                  LATAbits.LATA1
#define IO_RA1_PORT                 PORTAbits.RA1
#define IO_RA1_ANS                  ANSELAbits.ANSA1
#define IO_RA1_SetHigh()            do { LATAbits.LATA1 = 1; } while(0)
#define IO_RA1_SetLow()             do { LATAbits.LATA1 = 0; } while(0)
#define IO_RA1_Toggle()             do { LATAbits.LATA1 = ~LATAbits.LATA1; } while(0)
#define IO_RA1_GetValue()           PORTAbits.RA1
#define IO_RA1_SetDigitalInput()    do { TRISAbits.TRISA1 = 1; } while(0)
#define IO_RA1_SetDigitalOutput()   do { TRISAbits.TRISA1 = 0; } while(0)
#define IO_RA1_SetAnalogMode()      do { ANSELAbits.ANSA1 = 1; } while(0)
#define IO_RA1_SetDigitalMode()     do { ANSELAbits.ANSA1 = 0; } while(0)

// get/set IO_RA2 aliases
#define IO_RA2_TRIS                 TRISAbits.TRISA2
#define IO_RA2_LAT                  LATAbits.LATA2
#define IO_RA2_PORT                 PORTAbits.RA2
#define IO_RA2_ANS                  ANSELAbits.ANSA2
#define IO_RA2_SetHigh()            do { LATAbits.LATA2 = 1; } while(0)
#define IO_RA2_SetLow()             do { LATAbits.LATA2 = 0; } while(0)
#define IO_RA2_Toggle()             do { LATAbits.LATA2 = ~LATAbits.LATA2; } while(0)
#define IO_RA2_GetValue()           PORTAbits.RA2
#define IO_RA2_SetDigitalInput()    do { TRISAbits.TRISA2 = 1; } while(0)
#define IO_RA2_SetDigitalOutput()   do { TRISAbits.TRISA2 = 0; } while(0)
#define IO_RA2_SetAnalogMode()      do { ANSELAbits.ANSA2 = 1; } while(0)
#define IO_RA2_SetDigitalMode()     do { ANSELAbits.ANSA2 = 0; } while(0)
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
